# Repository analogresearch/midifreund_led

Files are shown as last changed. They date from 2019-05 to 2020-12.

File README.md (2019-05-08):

# midifreund_led

DC IN: 9..28 V 

Ansteuerung durch MIDI note 36 (C2) und eine Oktave dur hoch bis C3.
also:
36 38 40 41 43 45 47 48

MIDI channel und Programm werden binär über DIP Schalter gewählt.

MIDI: Ausnahme DIP Schalter 0000 = MIDI channel 16!

programme:  
0 triggert durch note on einen kurzen 100% Blitz der auf 0 ausfaded.  
1 triggert durch note on einen kurzen Blitz mit Starthelligkeit velocity der dann auf 0 ausfaded.  
2 note on schaltet Led mit Helligkeit velocity ein. Helligkeit kann dann mit aftertouch poly moduliert werden. note off schaltet Led aus.  

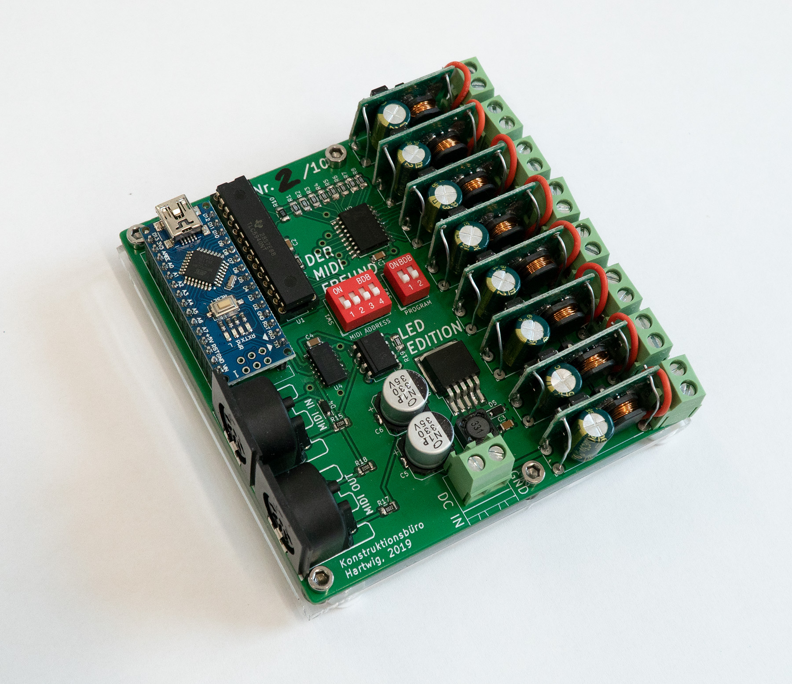
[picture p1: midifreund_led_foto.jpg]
ein Bild ein Foto


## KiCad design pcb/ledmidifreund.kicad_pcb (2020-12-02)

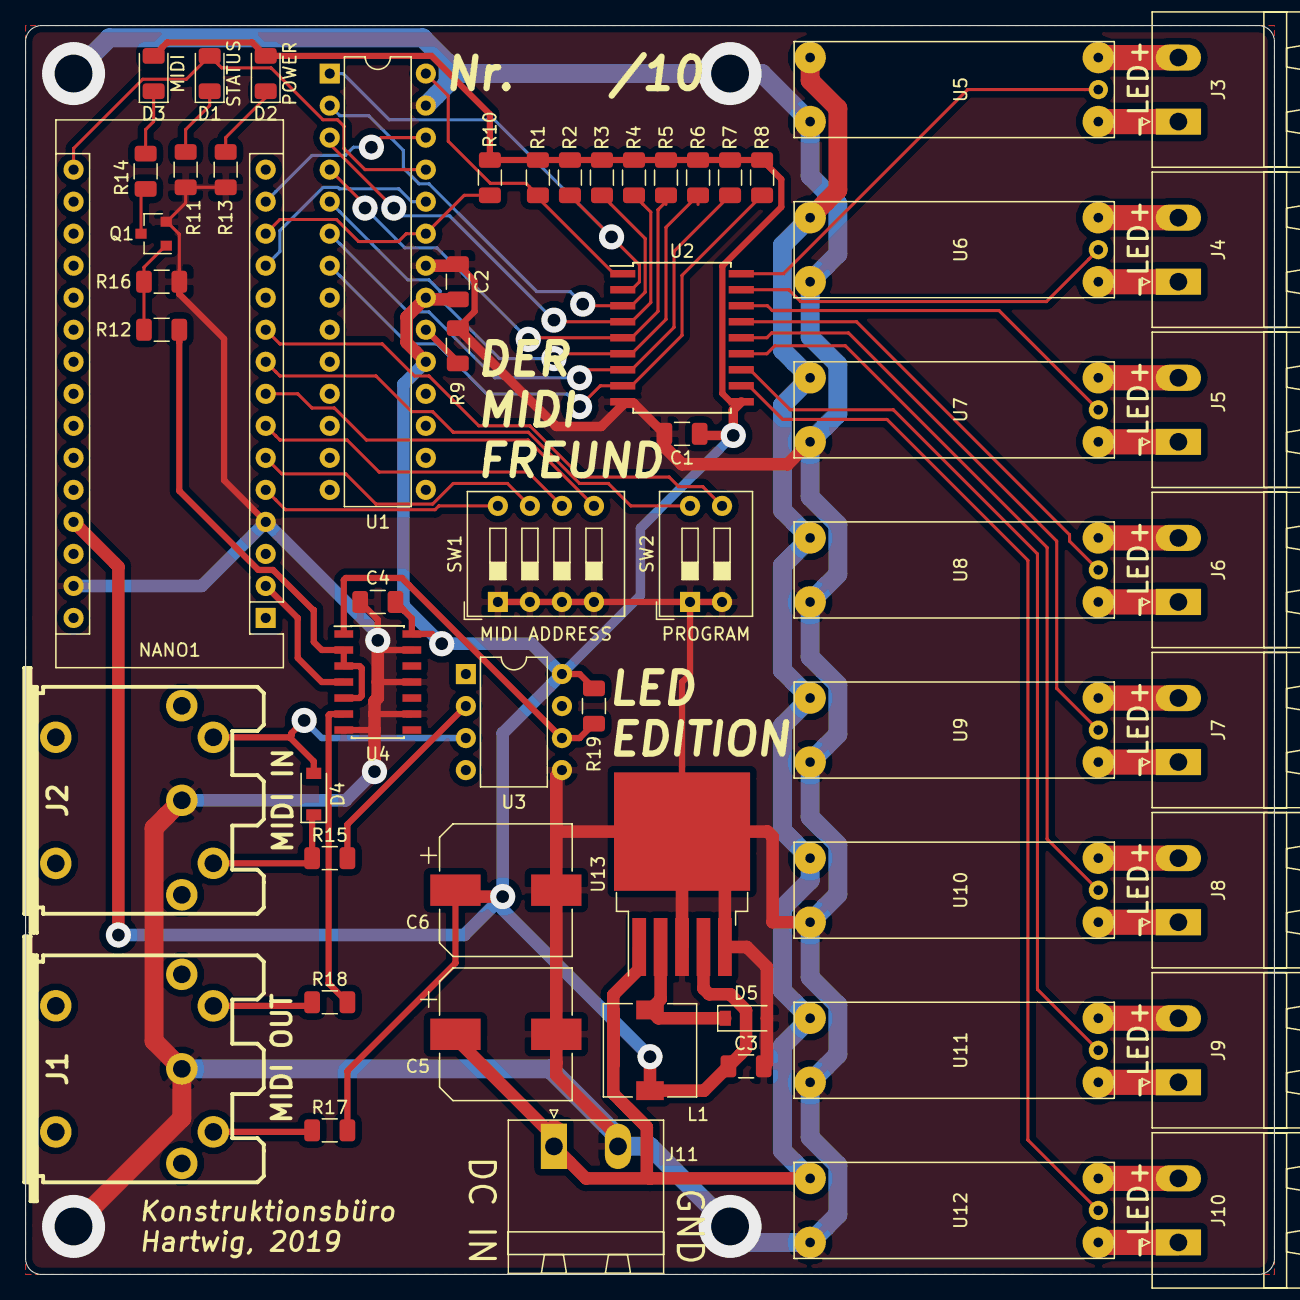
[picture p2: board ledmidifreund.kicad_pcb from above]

Board: 2 copper layers, 99.1 x 99.1 mm, 59 parts (0 on the bottom side), 61 nets.

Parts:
C1, C2, C3, C4: 100n; C_1206_3216Metric
C5, C6: 330uF; CP_Elec_10x10
D1: STATUS; LED_1206_3216Metric
D2: POWER; LED_1206_3216Metric
D3: MIDI; LED_1206_3216Metric
D4: 1N4148; D_SOD-123
D5: 1N5819; D_SOD-123
J1: MIDI OUT; MIDI_DIN5
J2: MIDI IN; MIDI_DIN5
J3, J4, J5, J6, J7, J8, J9, J10, J11: Conn_01x02; PhoenixContact_MSTBA_2,5_2-G-5,08_1x02_P5.08mm_Horizontal
L1: 330uH; L_7.3x7.3_H3.5
NANO1: Arduino_Nano_v3.x; Arduino_Nano
Q1: BSS138; SOT-23
R1, R2, R3, R4, R5, R6, R7, R8, R12: 1k; R_1206_3216Metric
R9: 2k2; R_1206_3216Metric
R10: 10k; R_1206_3216Metric
R11: 470; R_1206_3216Metric
R13, R14, R15, R17, R18: 220; R_1206_3216Metric
R16: 47k; R_1206_3216Metric
R19: 280; R_1206_3216Metric
SW1: SW_DIP_x04; SW_DIP_SPSTx04_Slide_9.78x12.34mm_W7.62mm_P2.54mm
SW2: SW_DIP_x02; SW_DIP_SPSTx02_Slide_9.78x7.26mm_W7.62mm_P2.54mm
U1: TLC5940NT; DIP-28_W7.62mm
U2: ULN2803A; SOIC-18W_7.5x11.6mm_P1.27mm
U3: 6N137; DIP-8_W7.62mm
U4: 74LS14; SOIC-14_3.9x8.7mm_P1.27mm
U5, U6, U7, U8, U9, U10, U11, U12: LEDREG1
U13: LM2575-5.0BU; TO-263-5_TabPin3

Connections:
+5V: C1.1, C2.1, C3.1, C4.1, C6.1, D2.2, D3.2, L1.2, NANO1.27, R1.1, R2.1, R3.1, R4.1, R5.1, R6.1, R7.1, R8.1, R10.2, R17.2, R19.1, U1.19, U1.21, U2.10, U3.8, U4.14, U13.4
GND: C1.2, C2.2, C3.2, C4.2, C5.2, C6.2, D5.2, J1.2, J2.2, J11.2, NANO1.4, NANO1.29, Q1.2, R9.2, R11.2, R13.1, R16.2, SW1.1, SW1.2, SW1.3, SW1.4, SW2.1, SW2.2, U1.22, U1.27, U2.9, U3.5, U4.7, U4.9, U4.11, U4.13, U5.3, U6.3, U7.3, U8.3, U9.3, U10.3, U11.3, U12.3, U13.3, U13.5
unnamed: D1.1, R11.1
unnamed: D1.2, NANO1.16, U1.25
unnamed: D2.1, R13.2
unnamed: D3.1, R14.1
unnamed: D4.1, J2.4, R15.1
unnamed: D4.2, J2.5, U3.3
unnamed: D5.1, L1.1, U13.2
unnamed: J1.4, R17.1
unnamed: J1.5, R18.1
unnamed: J3.1, U5.4
unnamed: J3.2, U5.1
unnamed: J4.1, U6.4
unnamed: J4.2, U6.1
unnamed: J5.1, U7.4
unnamed: J5.2, U7.1
unnamed: J6.1, U8.4
unnamed: J6.2, U8.1
unnamed: J7.1, U9.4
unnamed: J7.2, U9.1
unnamed: J8.1, U10.4
unnamed: J8.2, U10.1
unnamed: J9.1, U11.4
unnamed: J9.2, U11.1
unnamed: J10.1, U12.4
unnamed: J10.2, U12.1
unnamed: NANO1.2, U4.4
unnamed: NANO1.5, SW1.8
unnamed: NANO1.6, SW1.7
unnamed: NANO1.7, SW1.6
unnamed: NANO1.8, SW1.5
unnamed: NANO1.9, SW2.4
unnamed: NANO1.10, SW2.3
unnamed: NANO1.12, U1.24
unnamed: NANO1.13, R10.1, U1.23
unnamed: NANO1.14, U1.26
unnamed: Q1.1, R12.2, R16.1
unnamed: Q1.3, R14.2
unnamed: R1.2, U1.28, U2.1
unnamed: R2.2, U1.1, U2.2
unnamed: R3.2, U1.2, U2.3
unnamed: R4.2, U1.3, U2.4
unnamed: R5.2, U1.4, U2.5
unnamed: R6.2, U1.5, U2.6
unnamed: R7.2, U1.6, U2.7
unnamed: R8.2, U1.7, U2.8
unnamed: R9.1, U1.20
unnamed: R12.1, U4.2, U4.3, U4.5
unnamed: R15.2, U3.2
unnamed: R18.2, U4.6
unnamed: R19.2, U3.6, U4.1
unnamed: U2.14, U9.5
unnamed: U2.15, U8.5
unnamed: U2.16, U7.5
unnamed: U2.17, U6.5
unnamed: U2.18, U5.5
unnamed: U2.13, U10.5
unnamed: U2.12, U11.5
unnamed: U2.11, U12.5
VDD: C5.1, J11.1, U5.2, U6.2, U7.2, U8.2, U9.2, U10.2, U11.2, U12.2, U13.1

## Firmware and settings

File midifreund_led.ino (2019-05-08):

//////////////////////
/// der MIDIFREUND ///
/// LED edition //////
//////////////////////
/// version 0.65 /////
//////////////////////
/// stef ♥ 2019 //////
//////////////////////

#include <Tlc5940.h>
#include <MIDI.h>

MIDI_CREATE_DEFAULT_INSTANCE()

// log tabelle
static const uint8_t table[] PROGMEM = {
  0, 255  , 185  , 160  , 140  , 98 , 90 , 68 , 60 , 53 , 44 , 40 , 35 , 29 , 24 , 22 , 20 , 18 , 16 , 14 , 12 , 10 , 9  , 7  , 6  , 5  , 4  , 3  , 2  , 2  , 1  , 0  , 0
};
const uint8_t step_time = 10; // in ms
const uint8_t anz_chan = 8; // die ersten 8 von 16 in Benutzung

void start_fade(uint8_t channel);
void test_fades();
void reset_fades();
void step();

uint8_t midi_channel;
uint8_t program;

uint8_t max_steps = sizeof(table) / sizeof(table[0]);
uint8_t anz_steps = max_steps;
uint8_t fade_state[anz_chan];

void start_fade(uint8_t channel) {
  fade_state[channel] = 0;
}

void start_fade_velocity(uint8_t channel, uint8_t velocity) {
  fade_state[channel] = (int)map(velocity, 0, 127, anz_steps - 1, 0);
}

void test_fades() {
  for (uint8_t index = 0; index < anz_chan; index++)  {
    fade_state[index] = 0;
  }
}

void reset_fades() {
  for (uint8_t index = 0; index < anz_chan; index++)  {
    fade_state[index] = anz_steps - 1;
  }
}

void step() {
  for (uint8_t channel = 0; channel < anz_chan; channel++) {
    if (fade_state[channel] < (anz_steps - 1)) fade_state[channel]++;
    Tlc.set(channel, pgm_read_byte(&table[fade_state[channel]]) * 16);
  }
  Tlc.update();
}


void set_led(uint8_t channel, uint8_t velocity) {
  Tlc.set(channel, velocity * 32);
  Tlc.update();
}


void handler_note_on(byte channel, byte note, byte velocity)
{
  //digitalWrite(13, HIGH);
  switch (note) {
    case 36:  //C2
      if (program == 0) start_fade(0);
      if (program == 1) start_fade_velocity(0, velocity);
      if (program == 2) set_led(0, velocity);
      break;
    case 38: //d
      if (program == 0) start_fade(1);
      if (program == 1) start_fade_velocity(1, velocity);
      if (program == 2) set_led(1, velocity);
      break;
    case 40: //e
      if (program == 0) start_fade(2);
      if (program == 1) start_fade_velocity(2, velocity);
      if (program == 2) set_led(2, velocity);
      break;
    case 41: //f
      if (program == 0) start_fade(3);
      if (program == 1) start_fade_velocity(3, velocity);
      if (program == 2) set_led(3, velocity);
      break;
    case 43: //g
      if (program == 0) start_fade(4);
      if (program == 1) start_fade_velocity(4, velocity);
      if (program == 2) set_led(4, velocity);
      break;
    case 45: //h
      if (program == 0) start_fade(5);
      if (program == 1) start_fade_velocity(5, velocity);
      if (program == 2) set_led(5, velocity);
      break;
    case 47: //i
      if (program == 0) start_fade(6);
      if (program == 1) start_fade_velocity(6, velocity);
      if (program == 2) set_led(6, velocity);
      break;
    case 48: //j
      if (program == 0) start_fade(7);
      if (program == 1) start_fade_velocity(7, velocity);
      if (program == 2) set_led(7, velocity);
      break;
  }
}

void handler_note_off(byte channel, byte note, byte velocity)
{
  //digitalWrite(13, LOW);
  switch (note) {
    case 36:  //C2
      if (program == 2) set_led(0, 0);
      break;
    case 38: //d
      if (program == 2) set_led(1, 0);
      break;
    case 40: //e
      if (program == 2) set_led(2, 0);
      break;
    case 41: //f
      if (program == 2) set_led(3, 0);
      break;
    case 43: //g
      if (program == 2) set_led(4, 0);
      break;
    case 45: //h
      if (program == 2) set_led(5, 0);
      break;
    case 47: //i
      if (program == 2) set_led(6, 0);
      break;
    case 48: //j
      if (program == 2) set_led(7, 0);
      break;
  }
}

void handler_pressure(byte channel, byte note, byte pressure)
{
  //digitalWrite(13, LOW);
  switch (note) {
    case 36:  //C2
      if (program == 2) set_led(0, pressure);
      break;
    case 38: //d
      if (program == 2) set_led(1, pressure);
      break;
    case 40: //e
      if (program == 2) set_led(2, pressure);
      break;
    case 41: //f
      if (program == 2) set_led(3, pressure);
      break;
    case 43: //g
      if (program == 2) set_led(4, pressure);
      break;
    case 45: //h
      if (program == 2) set_led(5, pressure);
      break;
    case 47: //i
      if (program == 2) set_led(6, pressure);
      break;
    case 48: //j
      if (program == 2) set_led(7, pressure);
      break;
  }
}

void set_address() { // MIDI Schalter auslesen
  midi_channel = !digitalRead(2) + (!digitalRead(8) << 1) + (!digitalRead(4) << 2 ) + (!digitalRead(5) << 3);
  if (midi_channel == 0) midi_channel = 16;
}

void set_program() { // Programmschalter auslesen
  program = !digitalRead(6) + (!digitalRead(7) << 1);
}

void setup() {
  pinMode(2, INPUT_PULLUP);

  //pinMode(3, INPUT_PULLUP);
  pinMode(8, INPUT_PULLUP);

  pinMode(4, INPUT_PULLUP);
  pinMode(5, INPUT_PULLUP);
  pinMode(6, INPUT_PULLUP);
  pinMode(7, INPUT_PULLUP);
  pinMode(13, OUTPUT);
  set_address();
  set_program();

  MIDI.setHandleNoteOn(handler_note_on);
  MIDI.setHandleNoteOff(handler_note_off);
  MIDI.setHandleAfterTouchPoly(handler_pressure);
  Tlc.init();
  reset_fades();
  MIDI.begin(midi_channel);
  //test_fades();
}

void loop() {
  if ((program == 0) || (program == 1)) {
    step();
    unsigned long now = millis();
    while (millis() < (now + step_time)) MIDI.read();
  }
  else {
    MIDI.read();
  }
}
